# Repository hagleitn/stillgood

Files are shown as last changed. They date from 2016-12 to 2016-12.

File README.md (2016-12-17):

# still good?

Ever wonder if that piece of fish in the fridge is still good? How long has it been in there? Well, build one of these and stick it on your leftovers. StillGood will keep count of the days for you. No more guessing.

Stillgood

# Usage

If the display is off a single button press will bring it back to life. The display will turn off every 5 minutes to preserve power. Once activated the display will show the number of days since the last reset. The display only shows two digits, so it will wrap around every 100 days.

## Reset

When the display is active a push of the button will reset the number to "0". Count up will start again.

## Setting the number manually

A long press will enter into manual adjust mode. The number on the display starts blinking, which indicates the device is ready to receive clicks to increase the count. If no button presses are received for 5 seconds the device returns to normal operation.

## Changing the interval

By default the device counts up by one every day. However stillgood can also count every hour, minute or second. A double click on the button will cycle through the different modes. The display will indicate which mode is active after the change (d for day, h for hour, m for minute, s for second).

# Building one

Still good isn't hard to build but requires a fair amount of soldering because of the 2 digit 7 segment display. Here's the bill of materials

* Arduino pro mini, 3v 8Mhz 

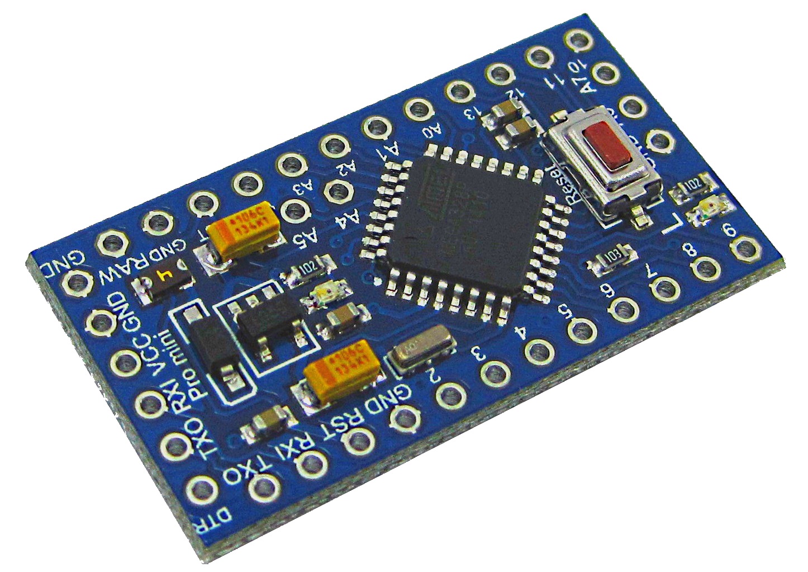
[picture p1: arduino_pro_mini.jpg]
arduino


* 0.36", Common Anode, 2 digit, 7 segment, 10 pin display 

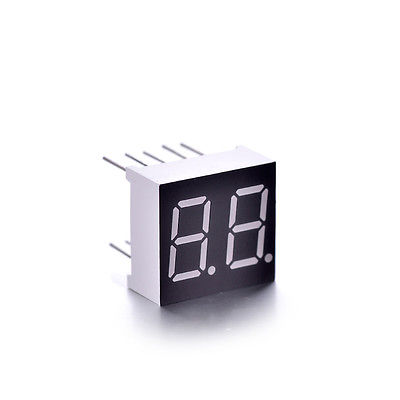
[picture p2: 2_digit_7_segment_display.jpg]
display


* Push button, momentary switch (6x6mm)

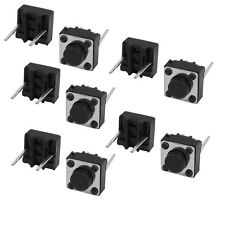
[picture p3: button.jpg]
button


* 2 resistors (2k is a good starting point, depending on how bright you want the display)

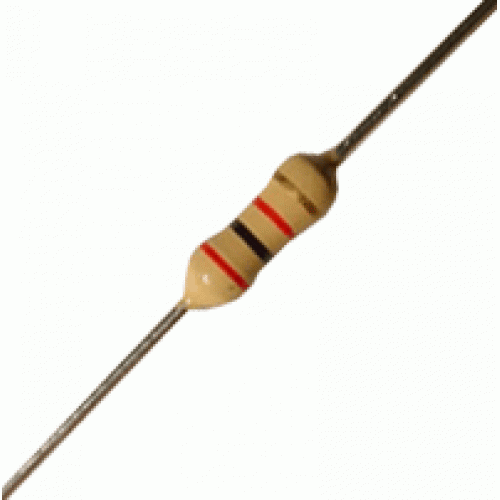
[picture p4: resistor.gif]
resistor


* Battery, CR 2032

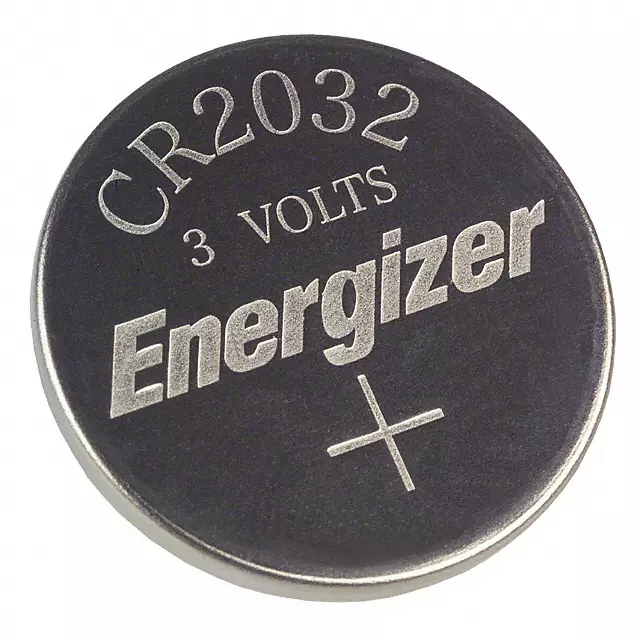
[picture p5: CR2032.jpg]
battery


* Wire to connect everything.

## Preparing the arduino

In order to reduce the power consumption of the arduino it's best to remove the voltage regulator and the led. In order to save space and avoid unwanted resets, I also remove the reset button. LED and button can be removed with a hobby knife. I remove the voltage regulator with needle nose pliers.

After prep, simply flash the binaries onto the arduino.

## Hooking things up

The display has to be wired to the pins of the arduino as follows:

    11 4 5 7 6
     9 x 3 8 10

The first row is for the top row of the pins of the display looking at it from the front. The second row is for the bottom pins. 2nd pin from left on the bottom row, does not have to be connected (controls the decimal point).

The resistors have to be placed between pins 10 and 11 on the arduino and the respective pins of the display.

One side of the button has to be connected to the pin 2 the other to ground on the arduino.

Finally, the battery needs to be connected to VCC and GND. I solder wires directly onto the battery after using some sandpaper on it (Careful not to heat the battery up too much).

The display and button should snap into place in the enclosure. Some hotglue helps to keep it in. The battery (after wrapping it in electric tape) goes below the display, on top of the button. The arduino on top of that. That's it.

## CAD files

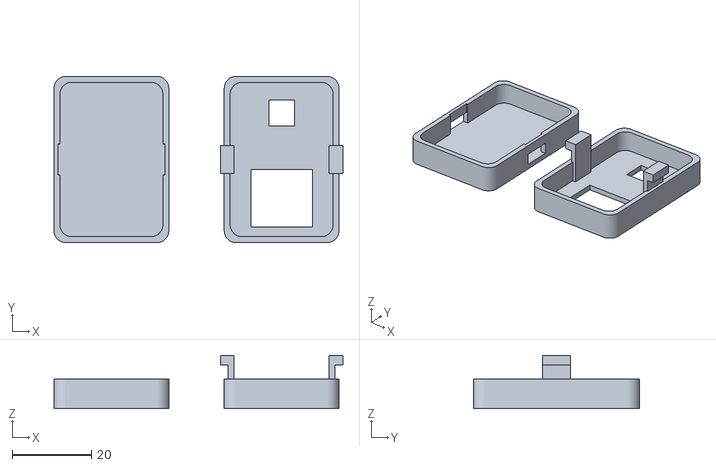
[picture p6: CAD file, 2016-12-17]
still_good.stl
73.0 x 42.0 x 13.5

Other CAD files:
still_good.scad

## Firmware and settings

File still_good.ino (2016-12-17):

#ifndef SIM
//#define DEBUG 1
#endif

#include "ClickHandler.h"
#include "Display.h"
#include "Timeline.h"

#ifndef SIM
#include "LowPower.h"
#endif

ts lastCheck;

volatile unsigned long count;
volatile unsigned long manual;

#define DAY    (HOUR * 24ul)
#define HOUR   (MINUTE * 60ul)
#define MINUTE (SECOND * 60ul)
#define SECOND (1000ul)

int resetPin = 2; // only 2 and 3 can be used w/ interrupt on mini

unsigned long countInterval;
unsigned long checkInterval;

unsigned long countIntervals[] = {DAY, HOUR, MINUTE, SECOND};
unsigned long checkIntervals[] = {MINUTE, MINUTE, SECOND, SECOND / 10};


enum _state_t {
  BASE,
  POWERSAVE,
  SHOW_INTERVAL,
  MANUAL_ENTRY
};

typedef _state_t state_t;

volatile state_t state;
volatile ts lastStateChange;

volatile int interval;

void setState(state_t s) {
#ifdef DEBUG
  switch(s) {
  case BASE:
    Serial.println("BASE");
    break;
  case POWERSAVE:
    Serial.println("POWERSAVE");
    break;
  case MANUAL_ENTRY:
    Serial.println("MANUAL_ENTRY");
    break;
  case SHOW_INTERVAL:
    Serial.println("SHOW_INTERVAL");
  }
#endif
  state = s;
  assignTime(&lastStateChange,now());
}

void reset() {

  resetTime();

  assignTime(&lastCheck,now());
  count = 0;
  manual = 0;
}

void setInterval(int i) {
  interval = i;
  checkInterval = checkIntervals[i];
  countInterval = countIntervals[i];
}

void changeInterval() {
  reset();
  setInterval((interval + 1) % 4);
}

void click() {
#ifdef DEBUG
  Serial.println("click");
#endif

  switch(state) {
  case BASE:
    reset();
    break;
  case POWERSAVE:
    setState(BASE);
    break;
  case SHOW_INTERVAL:
    // ignore
    break;
  case MANUAL_ENTRY:
    count++;
    manual++;
    setState(MANUAL_ENTRY);
    break;
  }
}

void doubleClick() {
#ifdef DEBUG
  Serial.println("double click");
#endif

  switch(state) {
  case BASE:
    changeInterval();
    setState(SHOW_INTERVAL);
    break;
  case POWERSAVE:
    setState(BASE);
    break;
  case SHOW_INTERVAL:
    changeInterval();
    setState(SHOW_INTERVAL);
    break;
  case MANUAL_ENTRY:
    count += 2;
    manual += 2;
    setState(MANUAL_ENTRY);
    break;
  }
}

void longClick() {
#ifdef DEBUG
  Serial.println("long click");
#endif

  switch(state) {
  case BASE:
    setState(MANUAL_ENTRY);
    break;
  case POWERSAVE:
    setState(BASE);
    break;
  case SHOW_INTERVAL:
    // ignore
    break;
  case MANUAL_ENTRY:
    count++;
    manual++;
    setState(MANUAL_ENTRY);
    break;
  }
}

void setup() {

#ifdef DEBUG
  Serial.begin(9600);
#endif

  setInterval(0);
  reset();

  setState(BASE);

  setupDisplay();

  setupClicks(resetPin, &click, &doubleClick, &longClick);
}

void loop() {
  updateTime();

  // handle user input
  updateClicks();

  if (pastInterval(&lastCheck,checkInterval)) {
    count = numberIntervals(now(), countInterval);
    count += manual;
    assignTime(&lastCheck,now());

#ifdef DEBUG
    Serial.print("Time: ");
    Serial.print(now()->t);
    Serial.print(",\t Passed: ");
    Serial.println(count);
#endif
  }

  // time transitions
  switch(state) {
  case BASE:
#ifndef SIM
    if (pastInterval(&lastStateChange, 2 * MINUTE)) {
      setState(POWERSAVE);
      clearAll();
    }
#endif
    break;
  case MANUAL_ENTRY:
    if (pastInterval(&lastStateChange, 5 * SECOND)) {
      setState(BASE);
    }
    break;
  case SHOW_INTERVAL:
    if (pastInterval(&lastStateChange, 2 * SECOND)) {
      setState(BASE);
    }
    break;
  default:
    // ignore
    break;
  }


  // update display
  switch(state) {
  case BASE:
    showCount(count);
    break;
  case POWERSAVE:
#ifndef SIM
    LowPower.idle(SLEEP_8S, ADC_OFF, TIMER2_OFF, TIMER1_OFF, TIMER0_ON,
                  SPI_OFF, USART0_OFF, TWI_OFF);
#else
    delay(8 * SECOND);
#endif
    break;
  case SHOW_INTERVAL:
    showInterval(interval);
    break;
  case MANUAL_ENTRY:
    if (((diff(now(),&lastStateChange)) / 300) % 2 == 0) {
      showCount(count);
    } else {
      showBytes(0, 0x00);
      showBytes(1, 0x00);
    }
    break;
  }
}

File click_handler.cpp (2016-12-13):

#include "click_handler.h"

#ifndef SIM
//#define DEBUG
//#include "hardwareSerial.h"
#endif

void (*click)();
void (*longClick)();
void (*doubleClick)();

#define LONG_CLICK_INTERVAL 1000
#define DOUBLE_CLICK_INTERVAL 250
#define MIN_INTERVAL 50

enum _click_state_t {
  BASE,
  HALF_CLICK,
  CLICK,
  CLICK_AND_HALF
};

typedef enum _click_state_t click_state_t;

int pin;

volatile click_state_t click_state;
volatile unsigned long lastClickStateChange;

volatile int clicks;
volatile int longClicks;
volatile int doubleClicks;

unsigned long now;

void setState(click_state_t s, unsigned long t) {
#ifdef DEBUG
  switch(s) {
  case BASE:
    Serial.println("BASE");
    break;
  case HALF_CLICK:
    Serial.println("HALF_CLICK");
    break;
  case CLICK:
    Serial.println("CLICK");
    break;
  case CLICK_AND_HALF:
    Serial.println("CLICK_AND_HALF");
  }
#endif

  click_state = s;
  lastClickStateChange = t;
}

int inInterval(unsigned long start, unsigned long length, unsigned long t) {
  return t >= start && t - start < length;
}

int pastInterval(unsigned long start, unsigned long length, unsigned long t) {
  return t >= start && t - start > length;
}

void rising() {
#ifdef DEBUG
  Serial.println("rising");
#endif

  switch(click_state) {
  case BASE:
    // ignore
    break;
  case HALF_CLICK:
    if (inInterval(lastClickStateChange, LONG_CLICK_INTERVAL, now)) {
      setState(CLICK, now);
    }
    if (pastInterval(lastClickStateChange, LONG_CLICK_INTERVAL, now)) {
      longClicks++;
      setState(BASE, now);
    }
    break;
  case CLICK:
    // ignore
    break;
  case CLICK_AND_HALF:
    if (inInterval(lastClickStateChange, LONG_CLICK_INTERVAL, now)) {
      doubleClicks++;
      setState(BASE, now);
    }
    if (pastInterval(lastClickStateChange, LONG_CLICK_INTERVAL, now)) {
      clicks++;
      longClicks++;
      setState(BASE, now);
    }
    break;
  }
}

void falling() {
#ifdef DEBUG
  Serial.println("falling");
#endif

  switch(click_state) {
  case BASE:
    setState(HALF_CLICK, now);
    break;
  case HALF_CLICK:
    // ignore
    break;
  case CLICK:
    if (!inInterval(lastClickStateChange, MIN_INTERVAL, now)) {
      setState(CLICK_AND_HALF, now);
    }
    break;
  case CLICK_AND_HALF:
    // ignore
    break;
  }
}

void change() {
  int val = digitalRead(pin);

  if (click_state == CLICK
      && pastInterval(lastClickStateChange, DOUBLE_CLICK_INTERVAL, now)) {
    setState(BASE, now);
    clicks++;
  }

  if (val == HIGH) {
    rising();
  } else {
    falling();
  }
}

void setupClicks(int _pin, void (*_click)(), void (*_doubleClick)(), void (*_longClick)()) {
  pin = _pin;
  click = _click;
  doubleClick = _doubleClick;
  longClick = _longClick;
  now = millis();
  setState(BASE, now);

  pinMode(pin, INPUT_PULLUP);
  attachInterrupt(digitalPinToInterrupt(pin), &change, CHANGE);
}

void updateClicks(unsigned long t) {

  now = t;

  if (click_state == CLICK
      && pastInterval(lastClickStateChange, DOUBLE_CLICK_INTERVAL, now)) {
    setState(BASE, now);
    clicks++;
  }

  while(clicks > 0) {
    click();
    clicks--;
  }

  while(doubleClicks > 0) {
    doubleClick();
    doubleClicks--;
  }

  while(longClicks > 0) {
    longClick();
    longClicks--;
  }
}

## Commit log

2016-12-03 adjust for 10 pin display
2016-12-07 debug printing
2016-12-11 update measurements
    [still_good.scad]
2016-12-11 power save
    [still_good.scad, still_good.stl]
2016-12-13 low power
2016-12-17 fix print message
    [still_good.stl]
